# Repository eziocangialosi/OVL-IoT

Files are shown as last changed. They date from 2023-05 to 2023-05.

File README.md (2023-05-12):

<a href="https://github.com/eziocangialosi/OpenVehicleLocator">
    OVL logo OVL
</a>

# OpenVehicleLocator - Tracker's electronic repository
Welcome on the electronic part of the OpenVehicleLocator project ! Here you will find all files related to the software on the microcontroller <br>
If you're not looking for the electronic part you can navigate between all the repositories in the [Project navigator](https://github.com/eziocangialosi/OpenVehicleLocator#project-navigation).

## Deployment
A whole page is available [here](https://doc.ovl-project.org/tracker-iot/page_deployment.html) to explain to you how to make your own tracker.

## Dependencies
You can access to all dependencies informations by this link : [Dependencies](https://doc.ovl-project.org/tracker-iot/page_dependencies.html)

## Documentation
The documentation of the project is available on <a href="https://doc.ovl-project.org/tracker-iot">https://doc.ovl-project.org</a>.

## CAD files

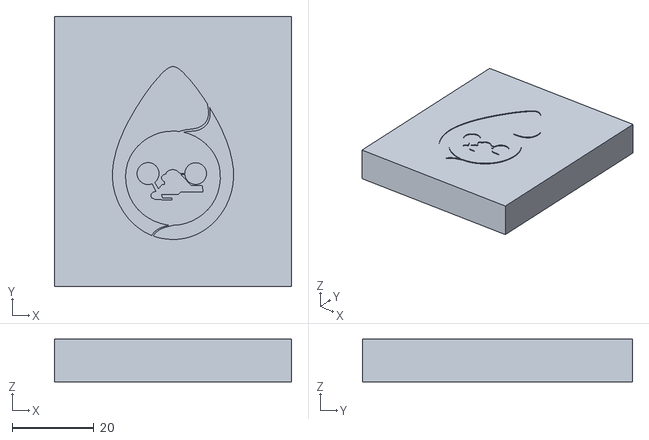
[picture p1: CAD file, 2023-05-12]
box-3d-model/up.stl
57.9 x 66.0 x 10.5

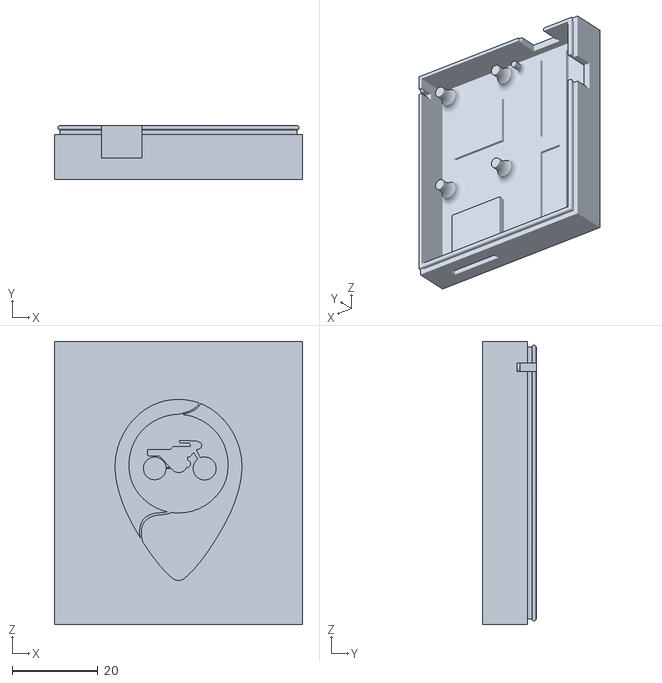
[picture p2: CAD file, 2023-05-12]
box-3d-model/base.stl
57.9 x 12.5 x 66.0

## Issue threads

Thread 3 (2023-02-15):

Add a class to manage errors (With error code thanks to RGB led and a blocking method)

eziocangialosi, 2023-02-15:
Add a class to manage errors :
Send error code with the RGB led
Add a blocking method to prevent execution of other part of the program when is needed

eziocangialosi, 2023-03-12:
Begin of developpement of the RGB error codes part 035fbf8

eziocangialosi, 2023-03-12:
Add a loop to handle fatal errors bc73425

eziocangialosi, 2023-04-05:
Modification in c3db72f :
Now when connection is lost, led is setted to purple
When try to handcheck, led is setted to orange

Closed 2023-05-04.

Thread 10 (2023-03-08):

Build a system to recharge the battery on vehicule's battery

eziocangialosi, 2023-03-08:

eziocangialosi, 2023-04-01:
Implemented in 8fbba6e

eziocangialosi, 2023-04-05:
Due to heat problems, the electronics of the charging part must be reviewed...

eziocangialosi, 2023-04-23:
New electronic schematic is available on [doc.ovl-project.org/tr](https://doc.ovl-project.org/tracker-iot/page_chargebat.html#autotoc_md4)
This electronic as not been yet tested, caution

eziocangialosi, 2023-05-11:
The system is now available on [doc.ovl-project.org/tr](https://doc.ovl-project.org/tracker-iot/page_chargebat.html).
It was tested and it work.

Closed 2023-05-11.

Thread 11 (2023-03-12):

The tracker can be stuck at the handcheck stage

eziocangialosi, 2023-03-12:
When the tracker try handcheck, it's waiting for a response, if there is none the tracker remains blocked

eziocangialosi, 2023-03-12:
Normaly patch with bc73425

eziocangialosi, 2023-04-01:
The patch in bc73425 create a new bug, the tracker tries to handcheck infinitely...
Limiting the number of attempts may be a solution

eziocangialosi, 2023-04-28:
Another case seems to trigger the same problem #17

eziocangialosi, 2023-04-28:
Note that handshake is misspelled everywhere in the project...
It is written "handcheck" instead of "handshake"

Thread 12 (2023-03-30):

The battery mesurment is not accurate

eziocangialosi, 2023-03-30:
The battery percentage is not reliable

eziocangialosi, 2023-05-04:
Currently, the battery percentage is accurate. So I will close the issue and if something gives us reason to doubt the reliability again we will reopen the issue

Closed 2023-05-04.

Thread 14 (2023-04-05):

Add an "TXT" frame to log misc events

eziocangialosi, 2023-04-05:
Add an "TXT=<string>" frame to allow tracker to send misc things (like current version running)

eziocangialosi, 2023-04-05:
Implemented in c47a4cb

Closed 2023-05-04.

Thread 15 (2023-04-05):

Make developper documentation with doxygen

eziocangialosi, 2023-04-05:
Build dev/code documentation with doxygen

eziocangialosi, 2023-04-05:
Add headers in c0e3d63

eziocangialosi, 2023-04-06:
Doc done on Communicator header and arduino project file 8c3d677

eziocangialosi, 2023-04-08:
Is done for LedIndicator header 9abab05

eziocangialosi, 2023-04-08:
Done for SerialDebug header 7a400c4

eziocangialosi, 2023-04-08:
Done for Locator public methods c07e9a5

eziocangialosi, 2023-04-09:
Locator header doc is done e3f8475

eziocangialosi, 2023-04-09:
Locator header doc is done e3f8475

eziocangialosi, 2023-04-09:
Done for tracker header 5c7ce13

eziocangialosi, 2023-04-23:
Developer documentation appears to be finished, available on doc.ovl-project.org/tracker-iot

Closed 2023-04-23.

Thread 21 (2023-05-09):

No protection against battery over-discharge

eziocangialosi, 2023-05-09:
They are no software protection against battery over-dischage.
The purpose of this protection is to prevent powerup when battery voltage is too low.
This should also turn off the tracker when the battery voltage gets too low.

eziocangialosi, 2023-05-10:
Implement in 1a5dbae

Closed 2023-05-10.

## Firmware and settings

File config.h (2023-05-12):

/**
 * @file        config.h
 * @brief       All the tracker configuration
 * @details     Here you will find all the configuration, if you require to edit a parameter do it here
 * @author      Ezio CANGIALOSI <eziocangialosi@gmail.com>
 * @version     v0.8.0-alpha
 * @date        04/2023
 */

#ifndef CONFIG_H
#define CONFIG_H

/*******************************************/
// GPRS config

/**
 * @def GSM_BAUD
 * Serial baud used ot communicate with gprs module
 */
#define GSM_BAUD 9600 

// Select your modem:
#define TINY_GSM_MODEM_SIM800
// #define TINY_GSM_MODEM_SIM808
// #define TINY_GSM_MODEM_SIM868
// #define TINY_GSM_MODEM_SIM900
// #define TINY_GSM_MODEM_SIM7000
// #define TINY_GSM_MODEM_SIM7000SSL
// #define TINY_GSM_MODEM_SIM7080
// #define TINY_GSM_MODEM_SIM5360
// #define TINY_GSM_MODEM_SIM7600
// #define TINY_GSM_MODEM_UBLOX
// #define TINY_GSM_MODEM_SARAR4
// #define TINY_GSM_MODEM_M95
// #define TINY_GSM_MODEM_BG96
// #define TINY_GSM_MODEM_A6
// #define TINY_GSM_MODEM_A7
// #define TINY_GSM_MODEM_M590
// #define TINY_GSM_MODEM_MC60
// #define TINY_GSM_MODEM_MC60E
// #define TINY_GSM_MODEM_ESP8266
// #define TINY_GSM_MODEM_XBEE
// #define TINY_GSM_MODEM_SEQUANS_MONARCH

/**
 * @def GSM_PIN
 * SIM card pin
 */
#define GSM_PIN ""

/**
 * @var const char APN
 * URL of your mobile operator apn
 */
const char APN[]      = "example.com";

/**
 * @var const char GPRS_USER
 * Your gprs user (if needed)
 */
const char GPRS_USER[] = "";

/**
 * @var const char GPRS_PSWD
 * Your gprs password (if needed)
 */
const char GPRS_PSWD[] = "";


/*******************************************/
// MQTT details

/**
 * @def MQTT_PORT
 * Broker port
 */
#define MQTT_PORT 1883

/**
 * @var const char BROKER
 * Broker URL or IP addr
 */
const char BROKER[]    = "example.com";

/**
 * @var const char TOPIC_RX
 * Rx Topic used for this tracker
 */
const char TOPIC_RX[]  = "topicRX";

/**
 * @var const char TOPIC_TX
 * Tx Topic used for this tracker
 */
const char TOPIC_TX[]  = "topicTX";

/**
 * @var const char MQTT_USER
 * Mqtt user for this tracker
 */
const char MQTT_USER[] = "mqtt_user";

/**
 * @var const char MQTT_PSWD
 * Mqtt password for this tracker
 */
const char MQTT_PSWD[] = "mqtt_pass";


/*******************************************/
// GPS config

/**
 * @def GPS_BAUD
 * Serial baud used for gps module
 */
#define GPS_BAUD 9600

/**
 * @def DISTANCE_TRIG
 * Distance from which we define that the position has changed, default 5 meters
 */
#define DISTANCE_TRIG 5


/*******************************************/
//Tracker misc params

/**
 * @def DEFAULT_VEH_CHG_STS
 * If the tracker can charge on vehicle battery by default
 */
#define DEFAULT_VEH_CHG_STS false

/**
 * @def DEFAULT_ECO_MODE_STS
 * If the tracker should be in ecomode by default
 */
#define DEFAULT_ECO_MODE_STS false

/**
 * @def DEFAULT_SAFE_ZONE_DIAM
 * Default diameter of the SafeZone, default 15
 */
#define DEFAULT_SAFE_ZONE_DIAM 15

/**
 * @def DEFAULT_INTERVAL
 * Default interval between 2 position refresh, default 5min
 */
#define DEFAULT_INTERVAL (5*60)

/**
 * @def DEFAULT_INTERVAL_WHEN_ALM
 * Default interval between 2 position refresh when alarm is on, default 5sec
 */
#define DEFAULT_INTERVAL_WHEN_ALM 5

/**
 * @def MINIMAL_INTERVAL
 * Minimal interval beetween 2 position refresh when alarm is off, default 30sec
 */
#define MINIMAL_INTERVAL 30

/**
 * @def DELAY_CHG_VEH
 * Default delay before charging on vehicle battery when is avail, default 5min
 */
#define DELAY_CHG_VEH (5*60)

/**
 * @def VEH_ALIM_SENSOR_PIN
 * Pin used to detect when the vehicle power is avail
 */
#define VEH_ALIM_SENSOR_PIN 4

/**
 * @def VEH_ALIM_RELAY_PIN
 * Pin used to command the charge on vehicle battery
 */
#define VEH_ALIM_RELAY_PIN 12

/**
 * @def LOW_VOLTAGE
 * Voltage in millivolts at which it is considered that the battery can be damaged (default 3100mV)
 */
#define LOW_VOLTAGE 3100

/*******************************************/
//Debug config

/**
 * @def USB_BAUD
 * Serial baud used to communicate with debug console
 */
#define USB_BAUD 115200

#endif

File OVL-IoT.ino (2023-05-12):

/**
 * @file        OVL-IoT.ino
 * @brief       Arduino loop & setup and instance creation of the tracker object
 * @author      Ezio CANGIALOSI <eziocangialosi@gmail.com>
 * @version     v0.8.0-alpha
 * @date        04/2023
 */
 
#include "Tracker.h"

Tracker g_iot; //!< Instance of Tracker class

void setup() {
  g_iot.beg();
}

void loop() {
  g_iot.actionInLoop();
}

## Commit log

2023-01-24 Add doc to Srv-IoT exchanges (protocol-Srv-IoT.md)
    Add an documentation file with all the frames exchanged between the server and tracker.
2023-01-25 Add protection status and rename alarm frame to protection
2023-01-25 Add somes frames
2023-01-26 Add PoC use 3 serial on esp32-E
    Using :
    - Serial(0) for USB/Debug
    - Serial2 for a external module
    - Serial1 is modified in the library to speak on GPIO 4 and 12
2023-01-26 Add frame for parameter request and fix somes misprints
2023-02-09 Initialization operational, communication with server "ok"
    - Init of tracker is working in fine conditions
    - Tracker succeed to communicate with server but not all the frame are implemented
    - Add of the config file (a gitignore will be add to ignore the changed to the config file for not overwrite the template)
2023-02-10 Correct default broker port in config.h
    [config.h]
2023-02-15 Edit Serial1 pin in HardwareSerial.h lib
    Due to an issue (It was necessary to unplug jumpers on Serial1 pins to run the program) Serial1 pins are been modifidied :
    TX1 4 --> 25
    RX1 12 --> 26
    This bug was probably due to the fact that ports 4 & 12 are touch ports...
    [SerialTransmitterESP32-E.ino]
2023-03-02 Implementation of Safe-Zone position request
    - The tracker can no boot without pin on sim card
2023-03-02 Revert "Add units-tests"
    This reverts commit ccdb75d71f6cb0bbaf70f91954f78aae55f2c4dd.
    [SerialTransmitterESP32-E.ino, gprs-sim800l-TinyGSM.ino, gps-neo6mv2-tinygpsplus.ino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]
2023-03-08 Try a new algorith ot know how to send position
    This one is based on the distance between the current position and the last knowed
2023-03-08 Remove two return to try to patch the GPRS&MQTT reconnection issue
    [Tracker.cpp]
2023-03-10 Beginning of RGB led error indicator
    [Tracker.cpp]
2023-03-11 Implementation of main led error codes
    - Update config.h template
    - Error codes implemented :
    - ORANGE : Init
    - RED : Cannot access to network, fatal
    - BLUE BLINK : No gps fix
    - GREEN BLINK : MQTT msg recived
    [Tracker.cpp]
2023-03-12 Add error codes, loop for fatal error, retry when handcheck failed
    - Add an error code when hand check failed once
    - Add a loop called when a fatal error occured
    - When the handcheck failed, the tracker retry it
    [Tracker.cpp, config.h]
2023-03-22 Add support of vehicle charge functionality
2023-04-04 Update position algorithm
    There was a bug with position algorithm in protection mode
    [Tracker.cpp, config.h]
2023-04-05 Edit position algorith cause of instability
    - Add parentheses in the times comparison
    - Edit the inital position timestamp to allow sending a position as soon the gps is fixed
    [Tracker.cpp]
2023-04-05 Patch of a deviation from the specifications
    If server try to enable protection mode while tracker haven't gps fix, tracker reply "PRT-ERR"
    Now, tracker enable it and reply "PRT-LIM" (Protection mode, LIMITED)
    The protection mode is so limited because the tracker haven't currently gps fix
    [Tracker.cpp]
2023-04-05 Patch of STG definition bug
    The settings could previously only be defined when the tracker asked for them.
    Now they can be all the time
    [Tracker.cpp]
2023-04-05 Removal of both return in tracker beg
    The 2 returns in the tracker beg are useless
    One has been totally removed (gprs one)
    The second has been replaced by a call to the LedIndicator kill loop
    [Tracker.cpp]
2023-04-05 Implementation of debug frames (TXT)
    Debug frames are now implemented (used for the moment for send tracker version and protection limited notice)
    (Use bool Communicator::sendDebugMqtt(String))
2023-04-06 Add doxygen comments on Communicator header and arduino project file
2023-04-08 Add doxygens comments in LedIndicator header
2023-04-28 Correct a misspelling on handshake and add doxyfile
    Handshake was written "handcheck"
    Doxyfile is used to generate documentation with doxygen
    [Tracker.cpp]
2023-05-04 Fix bugs in settings interpretation and protection method
    [Tracker.cpp]
2023-05-08 Add box STL files
    [base.stl, up.stl]
2023-05-10 Patch a bug in Tracker::mqtt_whenPrt
    The method was calling methods of Locator but this class wasn't initialized
    [Tracker.cpp]
2023-05-10 Add a protection against battery over-discharge
2023-05-11 Patch a bug with battery over-discharge proctection
    This bug was trigger the protection because of a wrong battery voltage value from the module
    [Tracker.cpp, config.h]
